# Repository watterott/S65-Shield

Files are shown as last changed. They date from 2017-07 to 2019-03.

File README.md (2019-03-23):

# S65-Shield
The S65-Shield is a plug-on module with color TFT-Display (176x132), microSD socket and rotary encoder for Arduino.

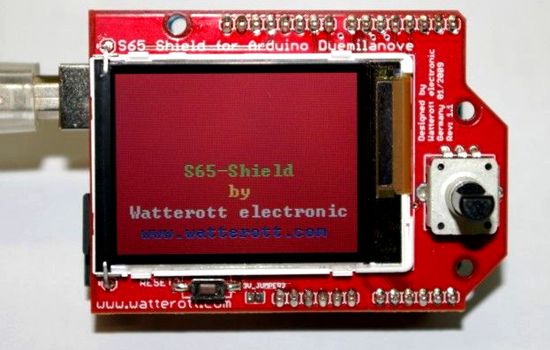
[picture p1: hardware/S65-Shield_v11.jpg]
S65-Shield


* Color-Display (176x132)
* Rotary-Encoder
* microSD Socket (SPI)
* Open-Source and released under the [Creative Commons Attribution Share-Alike License](https://creativecommons.org/licenses/by-sa/4.0/).
* **[Documentation on learn.watterott.com](https://learn.watterott.com)**

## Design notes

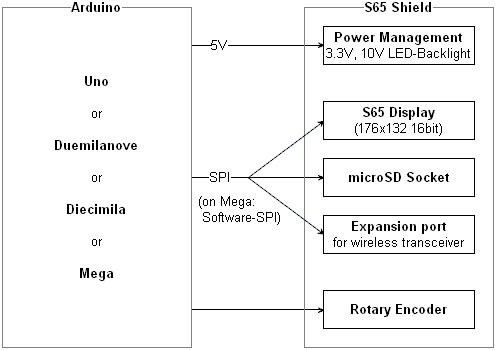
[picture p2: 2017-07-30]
hardware/hw_dia.png

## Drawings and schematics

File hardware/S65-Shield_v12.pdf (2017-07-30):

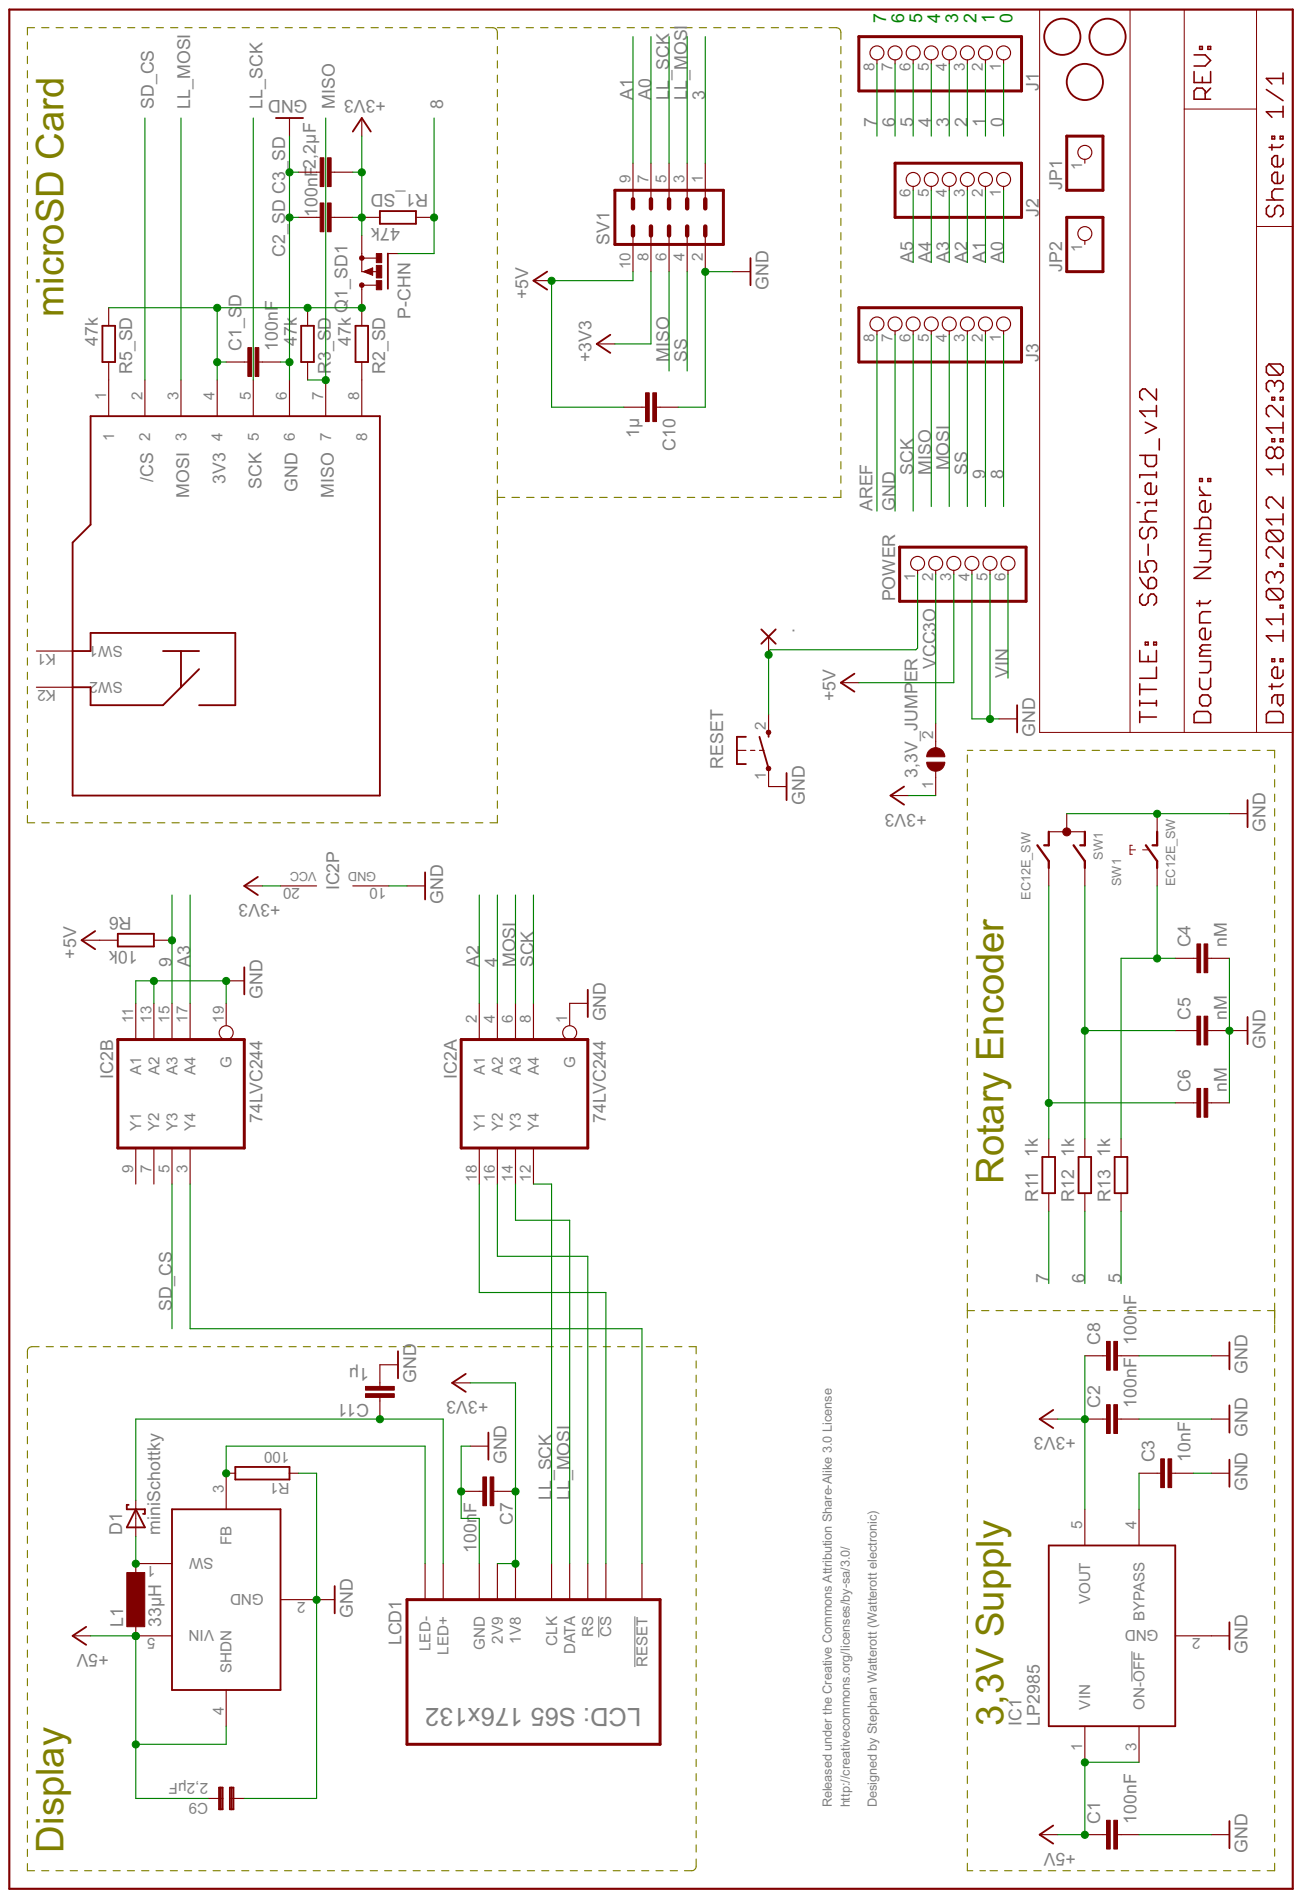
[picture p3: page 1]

http://creativecommons.org/licenses/by-sa/3.0/ Designed by Stephan Watterott (Watterott electronic) 8

GND GND GND

Released under the Creative Commons Attribution Share-Alike 3.0 License

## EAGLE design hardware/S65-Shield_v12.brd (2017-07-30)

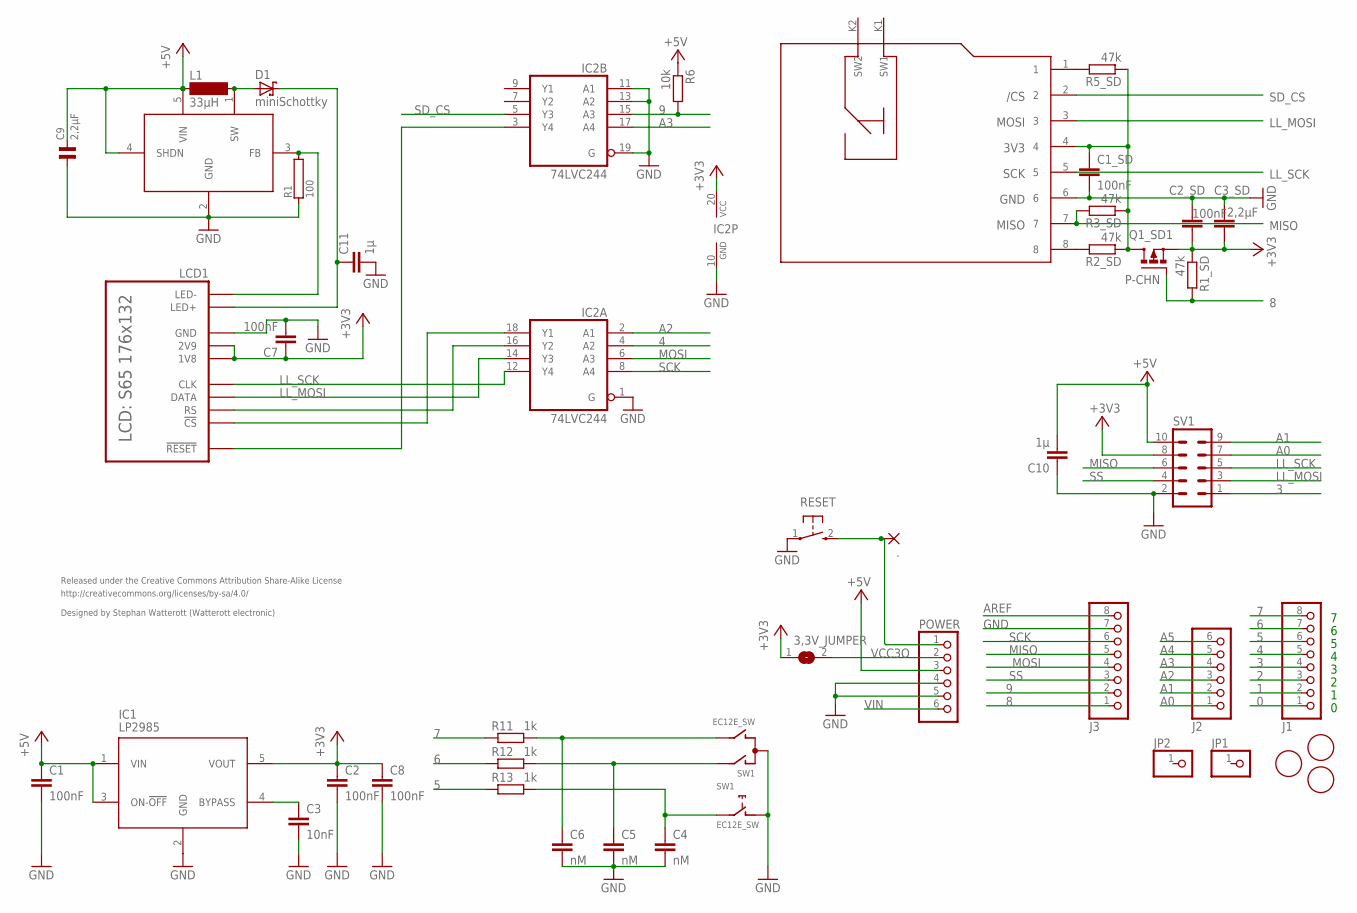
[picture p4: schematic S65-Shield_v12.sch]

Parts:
3,3V_JUMPER: SJ
.: SMD2; SMD1,27-2,54
C1, C1_SD, C2, C2_SD, C7: 100nF; C0603
C3: 10nF; C0603
C3_SD: 2,2µF; C0805
C4, C5, C6: nM; C0603
C8: 100nF; C0805
C9: 2,2µF; 0805
C10, C11: 1µ; C0603
D1: miniSchottky; D0603
IC1: LP2985; SOT23-5
IC2: 74LVC244; SO20W
J1, J3: PINHD-1X8; 1X08
J2: PINHD-1X6; 1X06
JP1, JP2: PINHD-1X1; 1X01
L1: 33µH; MS42
LCD1: S65
POWER: PINHD-1X6; 1X06
Q1_SD1: P-CHN; MICRO3
R1: 100; 0603
R1_SD, R2_SD, R3_SD, R5_SD: 47k; R0603
R6: 10k; R0603
R11, R12, R13: 1k; R0603
RESET: TAST_SMD1; SMD_TASTER
SD: MICRO-SD
SV1: ML10
SW1: EC12E_SW; ALPS_EC12E_SW
U$1, U$2, U$3: FIDUCIALMOUNT; FIDUCIA-MOUNT
U$4: LM2705; SOT23-5

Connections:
0: J1.1
1: J1.2
2: J1.3
3: J1.4, SV1.1
4: IC2.4 (A2), J1.5
5: J1.6, R13.1
6: J1.7, R12.1
7: J1.8, R11.1
8: J3.1, Q1_SD1.1 (G), R1_SD.2
9: IC2.15 (A3), J3.2, R6.2
+3V3: 3,3V_JUMPER.1, C2.1, C2_SD.2, C3_SD.2, C7.1, C8.1, IC1.5 (VOUT), IC2.20 (VCC), LCD1.1V8, LCD1.2V9, Q1_SD1.2 (S), R1_SD.1, SV1.8
+5V: C1.1, C9.2, C10.2, IC1.1 (VIN), IC1.3 (ON-!OFF), L1.1, POWER.3, R6.1, SV1.10, U$4.4 (SHDN), U$4.5 (VIN)
A0: J2.1, SV1.7
A1: J2.2, SV1.9
A2: IC2.2 (A1), J2.3
A3: IC2.17 (A4), J2.4
A4: J2.5
A5: J2.6
AREF: J3.8
GND: C1.2, C1_SD.2, C2.2, C2_SD.1, C3.2, C3_SD.1, C4.2, C5.2, C6.2, C7.2, C8.2, C9.1, C10.1, C11.2, IC1.2 (GND), IC2.1 (G), IC2.10 (GND), IC2.11 (A1), IC2.13 (A2), IC2.19 (G), J3.7, LCD1.GND, POWER.4, POWER.5, R1.1, RESET.1, SD.6, SV1.2, SW1.C, SW1.D (1), U$4.2 (GND)
LED+: C11.1, D1.1 (C), LCD1.LED+
LED-: LCD1.LED-, R1.2, U$4.3 (FB)
LL_MOSI: IC2.14 (Y3), LCD1.DATA, SD.3, SV1.3
LL_SCK: IC2.12 (Y4), LCD1.CLK, SD.5, SV1.5
MISO: J3.5, R3_SD.2, SD.7, SV1.6
MOSI: IC2.6 (A3), J3.4
unnamed: R5_SD.2, SD.1
unnamed: IC2.16 (Y2), LCD1.RS
unnamed: IC2.18 (Y1), LCD1.CS (!CS)
unnamed: IC2.3 (Y4), LCD1.RESET (!RESET)
unnamed: D1.2 (A), L1.2, U$4.1 (SW)
unnamed: C4.1, R13.2, SW1.E (2)
unnamed: C5.1, R12.2, SW1.A
unnamed: C6.1, R11.2, SW1.B
unnamed: C3.1, IC1.4 (BYPASS)
unnamed: ..1, POWER.1, RESET.2 (S)
unnamed: R2_SD.2, SD.8
SCK: IC2.8 (A4), J3.6
SD_3V3: C1_SD.1, Q1_SD1.3 (D), R2_SD.1, R3_SD.1, R5_SD.1, SD.4
SD_CS: IC2.5 (Y3), SD.2
SS: J3.3, SV1.4
VCC3O: 3,3V_JUMPER.2, POWER.2
VIN: POWER.6

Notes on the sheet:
Released under the Creative Commons Attribution Share-Alike License
http://creativecommons.org/licenses/by-sa/4.0/
Designed by Stephan Watterott (Watterott electronic)

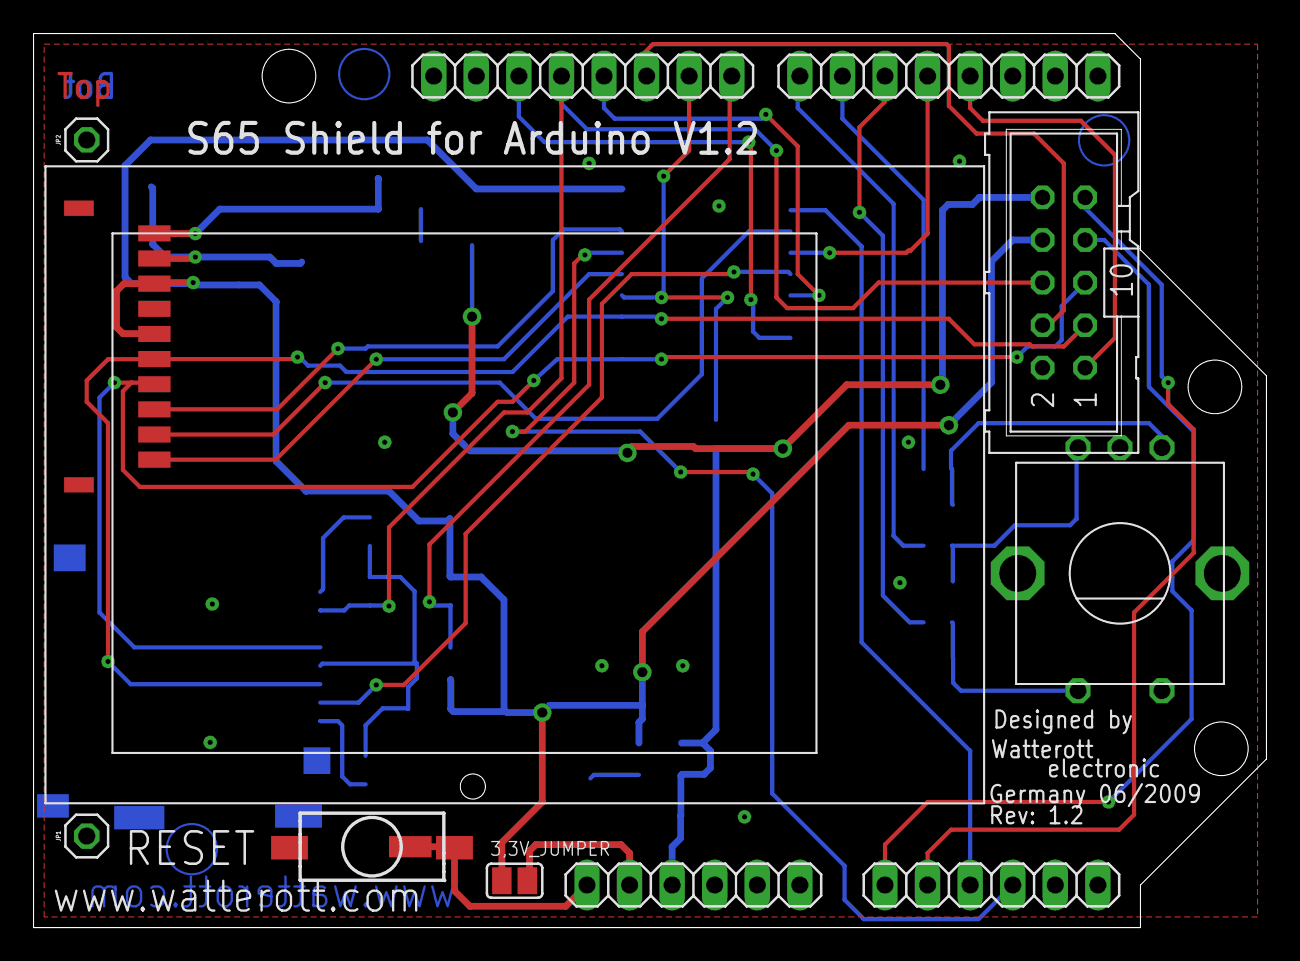
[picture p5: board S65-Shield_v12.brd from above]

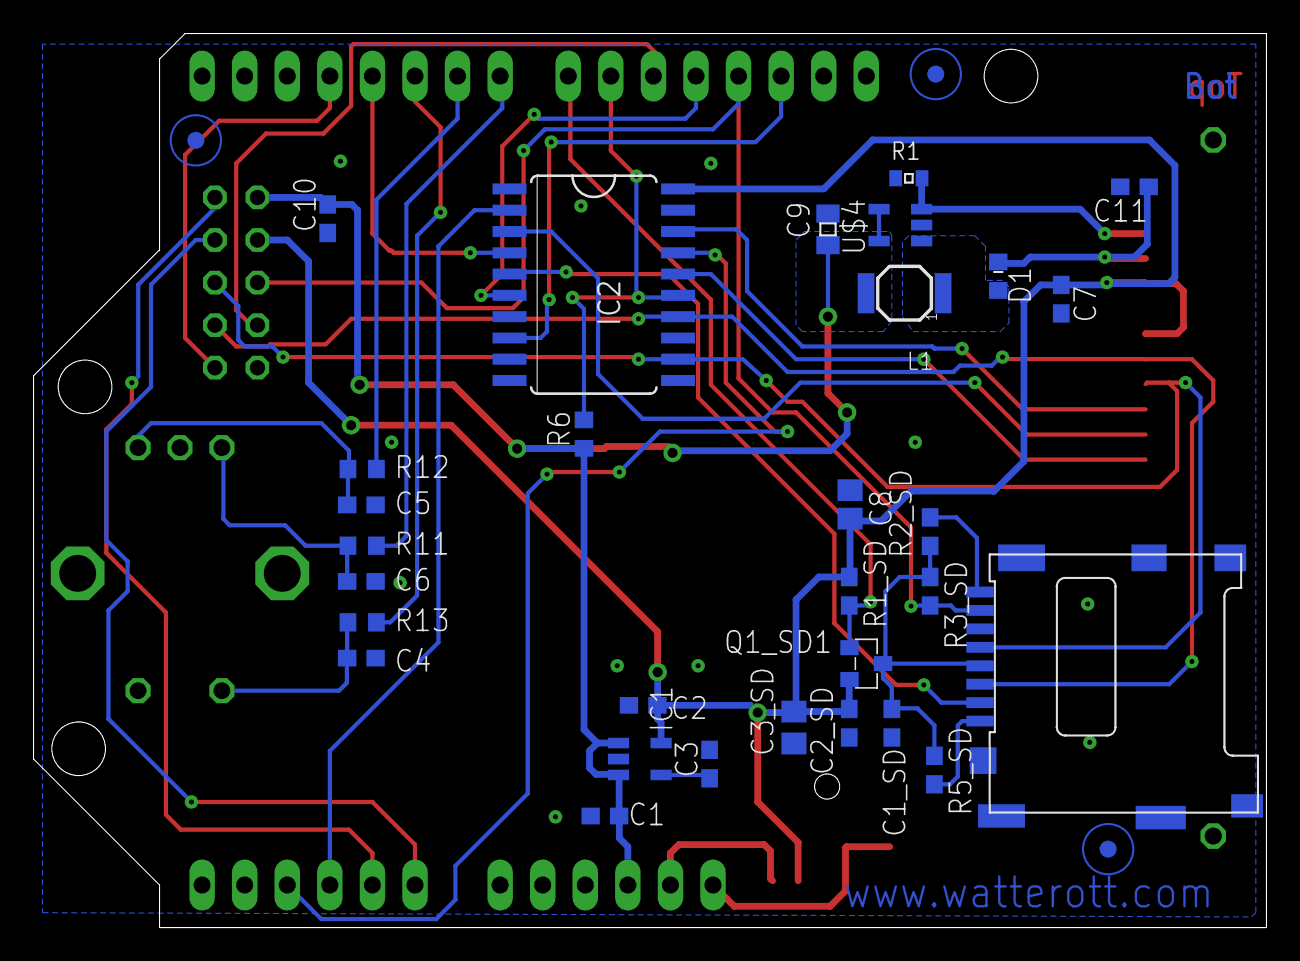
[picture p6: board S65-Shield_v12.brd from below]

Board: 2 copper layers, 73.6 x 53.3 mm, 45 parts (33 on the bottom side), 36 nets.
